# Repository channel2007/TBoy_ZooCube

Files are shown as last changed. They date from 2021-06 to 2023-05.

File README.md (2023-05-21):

# TBoy
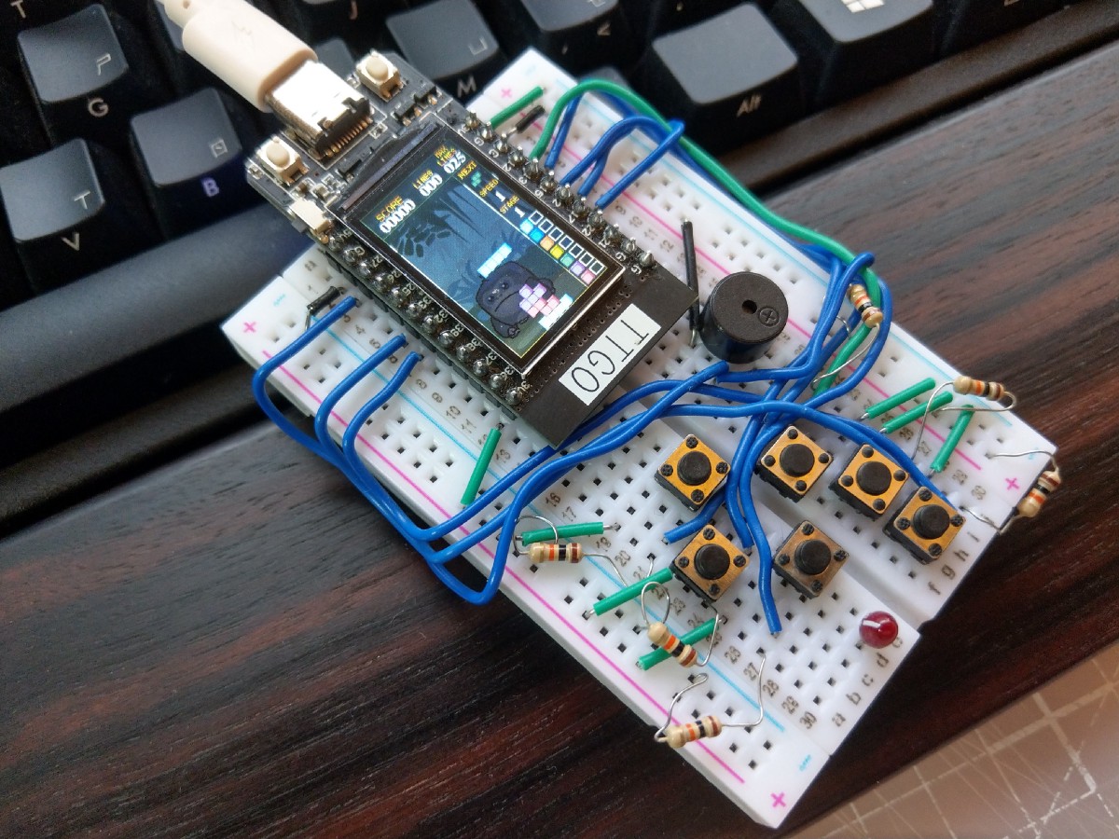
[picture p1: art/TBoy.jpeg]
alt TBoy TBoy


# 研發日誌
* 2023/05/21 新增Pong連線遊戲
* 2023/05/21 調整目錄路徑
* 2021/08/23 新增動物方塊韌體檔案(firmware目錄)
* 2021/07/23 修正遊戲圖形顏色不正確問題
* 2021/06/25 開放EasyEDA顯上線路圖檔案
* 2021/06/24 新增PCB板

# 前言
DIY了幾台網路大神們開源的掌機後，想想也該是時候來弄台原創掌機回饋一下社群了，也就是說新作的這台掌機會開源，希望對有興趣製作掌機的同好有所幫助。

# 準備材料
* TTGO T-Display ESP32 x  1
* 輕觸開關中兩腳 x 6
* 10kΩ電阻 x 6
* 蜂鳴器 x 1
* 麵包板 x 1
* 麵包板線一盒

# 線路圖
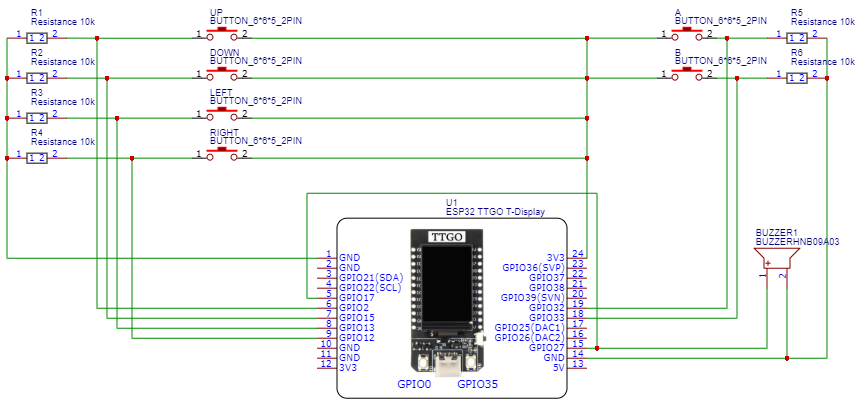
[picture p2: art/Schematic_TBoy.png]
alt TBoy TBoy


# 安裝套件
* [Bodmer/TFT_eSPI](https://github.com/Bodmer/TFT_eSPI)

# ZooCube遊戲介紹
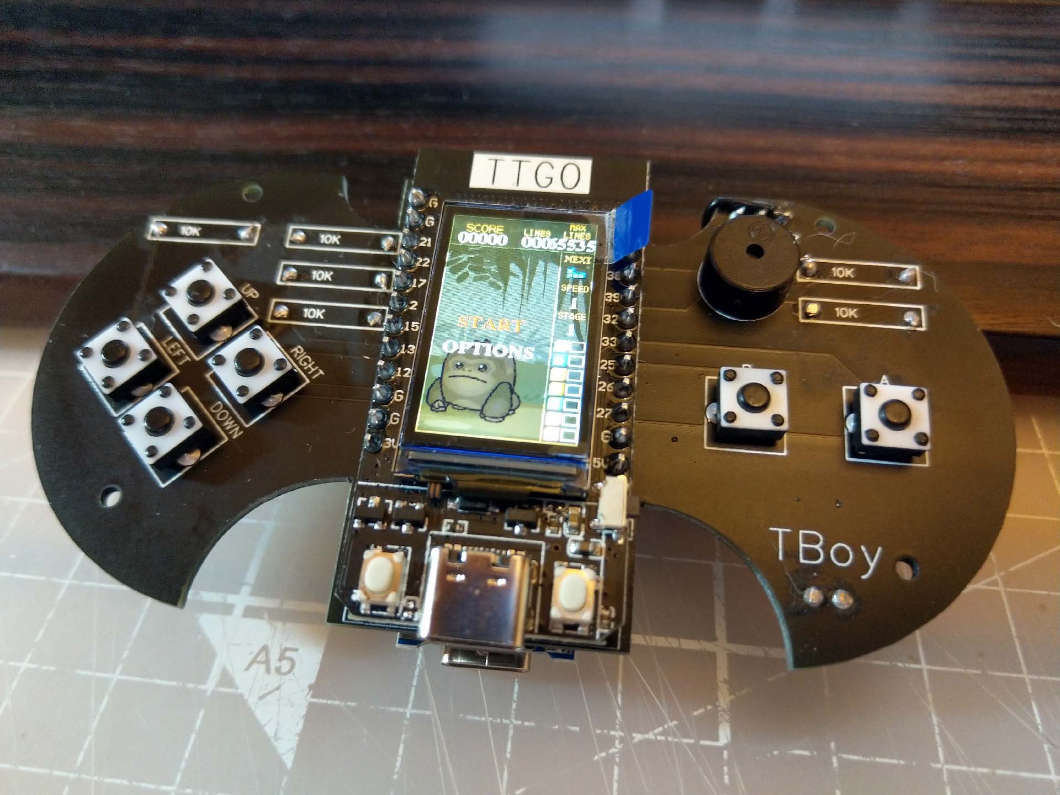
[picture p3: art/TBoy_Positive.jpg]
alt TBoy TBoy

* 遊戲玩法
玩家需要在10x20的空間內控制由上往下掉落的的七種方塊，利用旋轉方塊功能使掉落的方塊連成橫線，啟動消除方塊，如果在20列中都無法連成橫線消除方塊，遊戲就告結束。
遊戲中每消除一列會將每列的方塊顏色作累加，一共有七種顏色的方塊，每種顏色收集滿都會發動不同效果的技能。
隨著消除方塊列的數量越多，方塊下降的速度也會隨之變快，背景也會跟著變換圖片。

# 按鍵說明
* 左右按鈕：移動慢慢掉落中的方塊
* 下按鈕：讓方塊快速掉落
* A按鈕：順時鐘旋轉方塊
* B按鈕：逆時鐘旋轉方塊
* 開始按鈕：暫停遊戲
* 選擇按鈕：選項選單

# 使用網路資源
* [THE SPRITERS RESOURCE](https://www.spriters-resource.com/)
* [robsoncouto/arduino-songs](https://github.com/robsoncouto/arduino-songs)

# Pong連線遊戲介紹
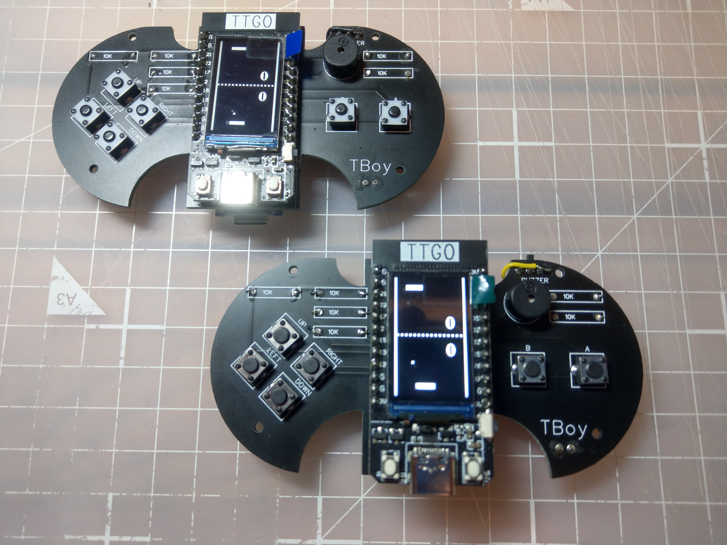
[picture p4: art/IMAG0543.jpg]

* 遊戲玩法
1. 遊戲場地 Pong遊戲的場地是一個矩形，有兩個玩家，一個在上方，一個在下方。每個玩家都有一個橫條（也稱為"板子"或"球拍"），可在水平方向移動。
2. 遊戲物件：遊戲中的主要物件是一個小球，它會在遊戲場地內以一定的速度移動，並且在撞到邊界或玩家的橫條時反彈。
3. 玩家控制：玩家可以左右移動他們的橫條，目的是讓小球反彈回對方的半場。玩家不能超過遊戲場地的邊界。
4. 得分規則：當一方玩家未能成功用橫條接住小球，使其反彈回對方半場時，對方就會得分。也就是說，如果小球碰到你的場地邊界，對方就獲得一分。獲得一定分數的玩家（例如10分）將獲得勝利。
5. 遊戲流程 遊戲開始時，小球從場地中央或隨機的一個點發出，向任一方向移動。遊戲繼續進行，直到一名玩家贏得遊戲，然後開始新的一局

# 按鍵說明
* 上下按鈕：選1P或2P
* 左右按鈕：左右移動板子
* A按鈕：確定、開始遊戲、遊戲中按住加速板子左右移動
* Start按鈕：無敵(球掉落底部自動反彈)
* Select按鈕：自動玩(板子自動追著球的X座標移動)

# PCB板準備材料
* TTGO T-Display ESP32 x 1
* 輕觸開關中兩腳 x 6
* 10kΩ電阻 x 6
* 無源蜂鳴器9*5.5MM  x 1
* 鋰電池充電板模組 TYPE-C USB介面充電保護二合一 x 1
* XH2.54-2P/針座/彎針/白色插件 2.54間距 x 1
* XH2.54-6P/針座/彎針/白色插件 2.54間距 x 1
* 200mAH、3.7V 聚合物鋰電池 x 1
* 滑動開關三腳二檔微型開關 x 1

# EasyEDA線路圖連接
[EasyEDA - TBoy](https://oshwlab.com/channel2007/tboy)

# PCB線路圖
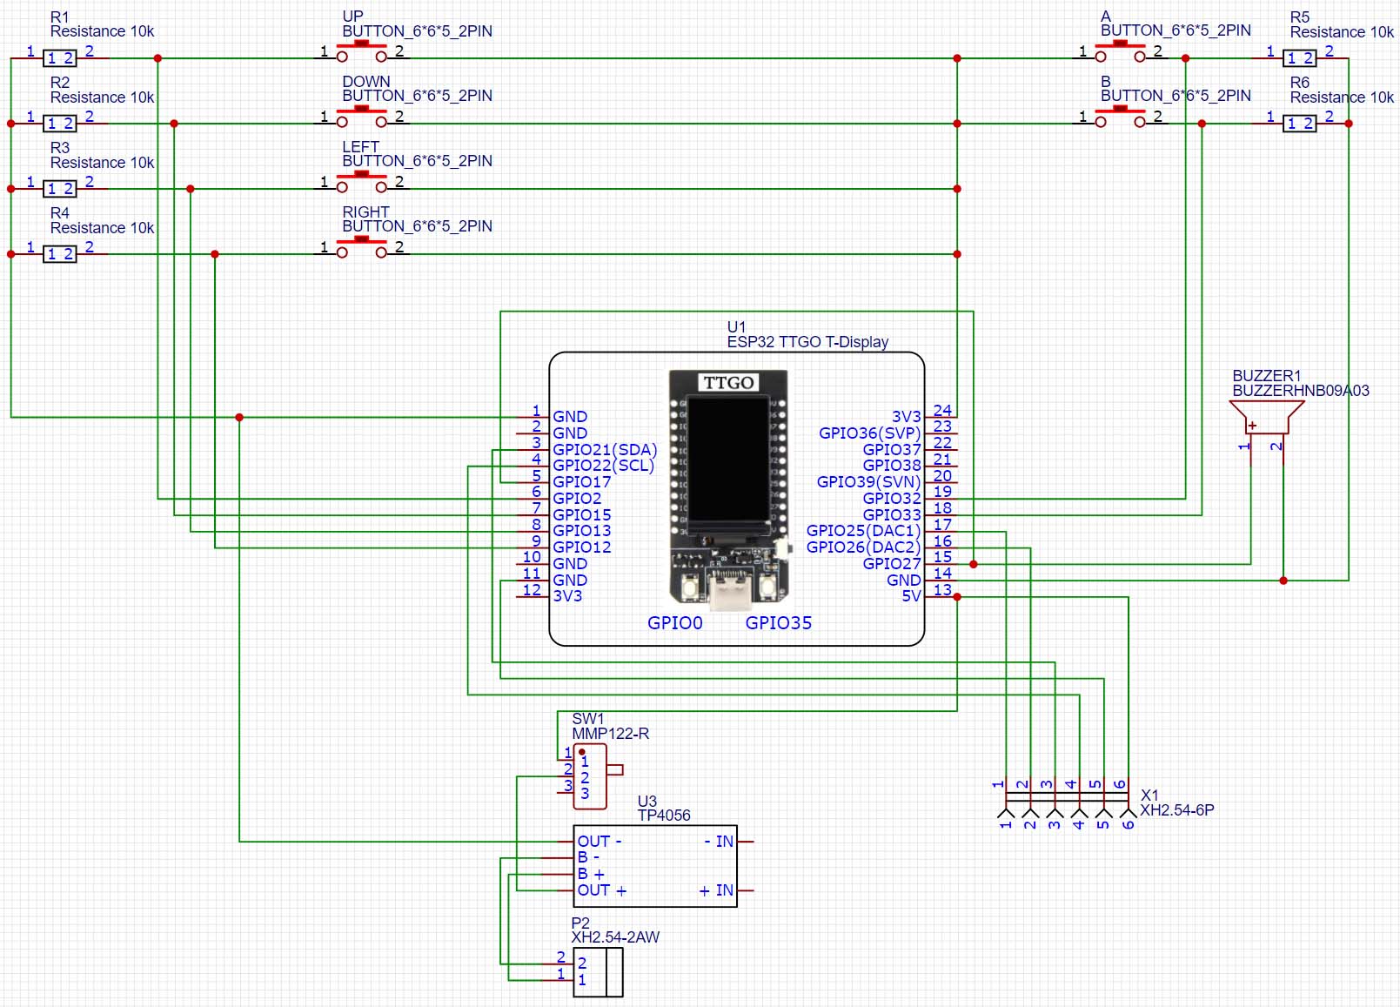
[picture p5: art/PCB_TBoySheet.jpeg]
alt TBoy TBoy

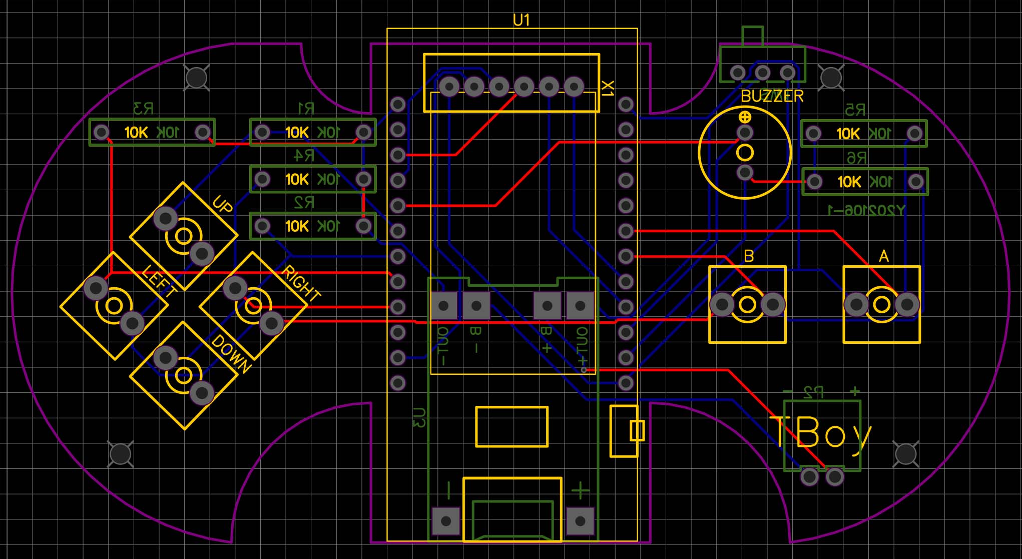
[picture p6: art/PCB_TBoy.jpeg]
alt TBoy TBoy


# 實機照
alt TBoy TBoy
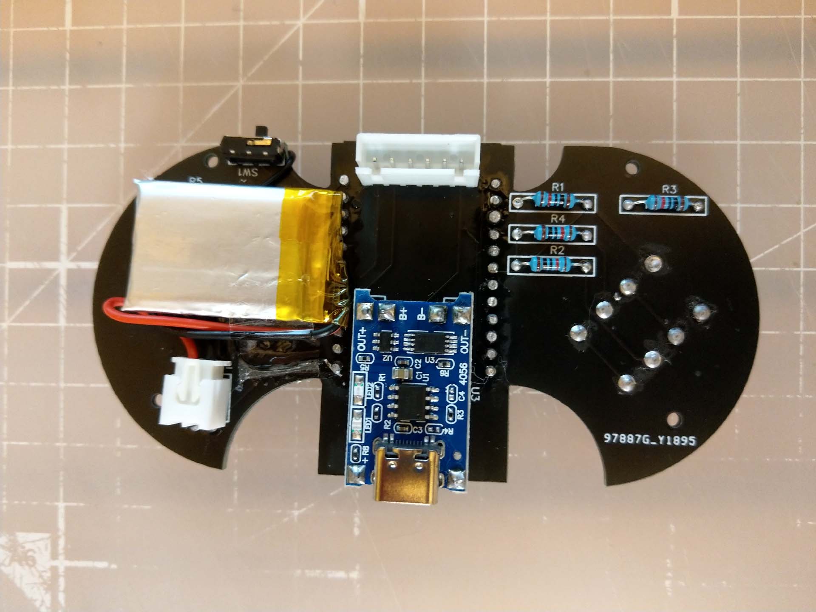
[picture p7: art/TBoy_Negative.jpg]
alt TBoy TBoy


# 詳細解說可以參考筆者寫的文章
[【掌機】原創掌機TBoy](https://vocus.cc/article/60bd70f7fd8978000182d0db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)

# 官方紛絲團 
[無限升級](https://www.facebook.com/unlimited.upgrade/posts/2840132506240869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)

# 官方Youtube
[無限升級](https://www.youtube.com/channel/UC4reRKznNk1CcjZfxKUdMuw)

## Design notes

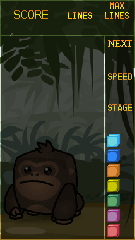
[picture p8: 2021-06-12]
art/ZooCube/background1.png

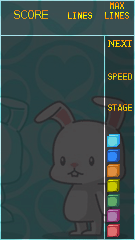
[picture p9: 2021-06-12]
art/ZooCube/background4.png

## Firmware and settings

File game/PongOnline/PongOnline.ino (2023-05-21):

//========================================================
// 功能：Pong連線遊戲 - 主程式.
//
//========================================================
#include <TFT_eSPI.h>
#include <SPI.h>

#include "Free_Fonts.h" 
#include "esp32_wifi_tcp.h"
#include "Joystick.h"
// 0:FPS.
// 1:計算FPS.
// 2:閃爍字.
#include "ClockSystem.h"

#define PADDLE_WIDTH 32           // 板子寬長.
#define PADDLE_HEIGHT 10

#define BALL_WIDTH 4              // 球寬長.
#define BALL_HEIGHT 4

#define WIN_SCORE 10              // 贏幾局結束遊戲.

// 遊戲模式.
typedef enum{
  GAME_SELECT=0,    // 選1P、2P.  
  GAME_CONNECTING,  // 等待連線.
  GAME_BEGIN,       // 準備開始遊戲.
  GAME_PLAY,        // 開始遊戲.
  GAME_OVER         // 遊戲結束.
} GameMode;

// box結構.
typedef struct {
    int x;
    int y;
    int w;
    int h;    
} Box;

// 球結構.
typedef struct {
    double x;
    double y;
    double prevX;
    double prevY;
    int w;
    int h;        
} Ball;

// 建立wifi物件.
esp32_wifi_tcp tcp( true, "ESP32-AP", "12345678");
// SPI.
TFT_eSPI tft = TFT_eSPI(); 
// 備頁.
TFT_eSprite doubleBuffer = TFT_eSprite(&tft);

// 搖桿1P.
Joystick joystick_1P(2, 15, 13, 12, 32, 33, 35, 0);
// 時脈系統.
ClockSystem clockSystem;

// 板子(1P、2P).
Box board1P;
Box board2P;
// 球.
Ball ball;

// fps.
uint8_t fps=0;
uint8_t fpsTemp=0;

// 是否為Server模式(1P).
bool isServer = true;
// 閃爍字.
bool flashFont = true;

// 分數.
uint8_t score1P = 0;
uint8_t score2P = 0;
// 球-移動速度.
double speed = 2.0;
// 球-設定初始反射角度.
double reflection_angle = 45.0;  

// 行進時間(時間越長球速越快).
int travelTime = 0;
// 無敵.
bool invincible= false;
// 自動玩遊戲.
bool autoPlay = false;
// 板子移動速度.
int boardSpeed = 4;

// 字串.
char buf[64]; 

// 設定初始狀態.
GameMode gameMode = GAME_SELECT;

//-----------------------------------------------------
// 拆解字串.
//-----------------------------------------------------
void split(const char *data, char separator, char result[][100], int *resultCount, int maxResultCount) {
  int len = strlen(data);
  int start = 0;
  int end = 0;
  *resultCount = 0;
  for (int i = 0; i < len; i++) {
    if (data[i] == separator) {
      end = i;
      int length = end - start;
      if (length > 0) {
        strncpy(result[*resultCount], &data[start], length);
        result[*resultCount][length] = '\0';
        (*resultCount)++;
        if (*resultCount >= maxResultCount) {
          break;
        }
      }
      start = i + 1;
    }
  }  
  if (*resultCount < maxResultCount) {
    int length = len - start;
    if (length > 0) {
      strncpy(result[*resultCount], &data[start], length);
      result[*resultCount][length] = '\0';
      (*resultCount)++;
    }
  }
}

//-----------------------------------------------------
// 判斷球與板子碰撞.
//-----------------------------------------------------
bool didCollide(Box p, Ball b){
  // 首先檢查球是否在板子的左邊或右邊之外，如果是，則不可能發生碰撞
  if ((b.x + BALL_WIDTH / 2.0) < p.x || (b.x - BALL_WIDTH / 2.0) > (p.x + PADDLE_WIDTH)) {
    return false;
  }
  // 檢查球是否在板子的上邊或下邊之外，如果是，則不可能發生碰撞
  if ((b.y + BALL_HEIGHT / 2.0) < p.y || (b.y - BALL_HEIGHT / 2.0) > (p.y + PADDLE_HEIGHT)) {
    return false;
  }
  // 如果以上條件都不成立，則表示球與板子有重疊，即發生了碰撞
  return true;
}

//-----------------------------------------------------
// 更新球移動.
//-----------------------------------------------------
void updateBall(Ball* position, double* speed, double* reflection_angle) {
    // 遊戲中才進入處理球移動.
    if(gameMode != GAME_PLAY)
      return;
    
    // 計算球在x軸和y軸上的速度成分
    double dx = *speed * cos(*reflection_angle);
    double dy = *speed * sin(*reflection_angle);

    // 備份球舊座標(判斷碰撞用).
    position->prevX = position->x; 
    position->prevY = position->y;

    // 更新球的位置
    position->x += dx;
    position->y += dy;

    // 檢查是否碰到邊界，並反彈
    if (position->x < 4  || position->x > 127) {
      // 球碰到左右邊界，將反射角度反轉
      *reflection_angle = M_PI - *reflection_angle;
    }
    if (position->y < 0 || position->y > 240) {
      // 球碰到上下邊界，將反射角度反轉
      *reflection_angle = -(*reflection_angle);
      // 不是無敵才進入執行.
      if(!invincible){
        // 1P加分.
        if(position->y < 0){
          score1P++;        
        // 2P加分.
        }else if(position->y > 240){
          score2P++;
        }  
        // 初始球位置.
        position->x = position->prevX = 70; 
        position->y = position->prevY = 120;
        
        // 放慢球速.
        *speed = 2.0;
        //Serial.println((String)position->x+":"+position->y);      
      }      
    }
}

//-----------------------------------------------------
// 更新畫面.
//-----------------------------------------------------
void updateScreen(){
  // 牆壁-左.
  doubleBuffer.fillRect (  0, 0,  4,  240, 0xFFFF);    
  // 牆壁-右.
  doubleBuffer.fillRect (131, 0,  4,  240, 0xFFFF);
  // 牆壁-中.      
  for(int i=4; i<131; i+=8){
    doubleBuffer.fillRect (i, 118, 4,  4, 0xFFFF);
  }
  // 顯示分數.
  doubleBuffer.setFreeFont(FSB18);
  doubleBuffer.setTextColor(TFT_WHITE, TFT_BLACK);      
  sprintf(buf, "%d", score2P);
  doubleBuffer.drawCentreString(buf, 105,  80, GFXFF); // 2P.
  sprintf(buf, "%d", score1P);
  doubleBuffer.drawCentreString(buf, 105, 135, GFXFF); // 1P.  

  // 板子1P. 
  doubleBuffer.fillRect ( board1P.x, board1P.y, board1P.w,  board1P.h, 0xFFFF);
  // 板子2P. 
  doubleBuffer.fillRect ( board2P.x, board2P.y, board2P.w,  board2P.h, 0xFFFF);   
}

//-----------------------------------------------------
// 顯示連線訊息.
//-----------------------------------------------------
void connecting(){
  // 用全黑清除螢幕
  doubleBuffer.fillScreen(TFT_BLACK);
  doubleBuffer.setFreeFont(FSB9);
  doubleBuffer.setTextColor(TFT_WHITE, TFT_RED);
  doubleBuffer.drawCentreString("connecting...", 66, 40, GFXFF);
  // 更新畫面.
  updateScreen();  
}

//-----------------------------------------------------
// 板子超界修正.
//-----------------------------------------------------
void boardOverstep(){  
  if(board1P.x<4) 
    board1P.x = 4;          
  if(board2P.x<4) 
    board2P.x = 4;        
  if(board1P.x>99) 
    board1P.x = 99;          
  if(board2P.x>99) 
    board2P.x = 99;
}

//-----------------------------------------------------
// 移動板子.
//-----------------------------------------------------
void boardMove(){
  // 左.
  if (joystick_1P.GetButtonLeft(false)) {
    // 1P.
    if(isServer){
      board1P.x -= boardSpeed;
    // 2P.
    }else{
      board2P.x -= boardSpeed;
    }
    
  // 右.
  }else if (joystick_1P.GetButtonRight(false)) {
    // 1P.
    if(isServer){
      board1P.x += boardSpeed;
    // 2P.
    }else{
      board2P.x += boardSpeed;
    }        

  // 開關無敵.
  }else if (joystick_1P.GetButtonStart(true)) {
    invincible = !invincible;
    
  // 開關自動玩.
  }else if (joystick_1P.GetButtonSelect(true)) {
    autoPlay = !autoPlay;
        
  }

  // 快速移動板子.
  if (joystick_1P.GetButtonA(false)){
    boardSpeed = 12;
  }else{
    boardSpeed = 4;
  }
  
  // 板子超界修正.
  boardOverstep();  
}

//-----------------------------------------------------
// 1P、2P相互溝通.
//-----------------------------------------------------
void communicate(){
  // Server模式(1P).
  if(isServer){
    // 【Server傳送指令給Client】1P板子座標 - c1|x|bx|by|score1P|score2P|gameMode|
    sprintf(buf, "c1|%d|%f|%f|%d|%d|%d|", board1P.x, ball.x, ball.y, score1P, score2P, gameMode);
    tcp.send(buf);
          
    // 更新球.
    updateBall(&ball, &speed, &reflection_angle);
      
    // 如果球與板子發生碰撞就處理反彈.       
    if( didCollide(board1P, ball) || didCollide(board2P, ball)){
      // 反彈球.
      reflection_angle = -(reflection_angle);
      // 復原座標.
      ball.x = ball.prevX; ball.y = ball.prevY;
      // 開球時放慢速度，等碰到板子後恢復正常速度.
      if(speed == 2.0) speed = 4.0;
    }    
    //Serial.println(str);

    // 自動玩.
    if(autoPlay){
      board1P.x = ball.x -(PADDLE_WIDTH - BALL_WIDTH)/2;
    }
           
  // Client模式(2P).
  }else{
    //【Client傳送指令給Server】2P板子座標 - s1|x|
    sprintf(buf, "s1|%d|", board2P.x);
    tcp.send(buf);

    // 自動玩.
    if(autoPlay){
      board2P.x = ball.x-(PADDLE_WIDTH - BALL_WIDTH)/2;
    }    
  }
  // 板子超界修正.
  boardOverstep();  
}

//-----------------------------------------------------
// 重新開始遊戲.
//-----------------------------------------------------
void resetGame(){
  // 球.
  ball.x = ball.prevX = 70; ball.y = ball.prevY = 120;
  // 分數.
  score1P = 0;
  score2P = 0;
  // 球-移動速度.
  speed = 2.0;
  // 行進時間(時間越長球速越快).
  travelTime = 0;
  // 板子移動速度.
  boardSpeed = 4;  
}

//-----------------------------------------------------
// 解指令字串.
//-----------------------------------------------------
void decodingReceived(String received){
  char result[10][100];   // 用來存放分割後的字串，最多容納 10 個字串，每個字串長度最多 100 個字元.
  int resultCount = 0;    // 儲存分割後的字串數量.
  int n = 0;
  double d = 0.0;
  
  if(received=="")
    return;
    
  // 需要多一個字元來容納結尾的 null 字元
  char charArray[received.length() + 1];  

  // 將 String 轉換為 char 字元陣列
  received.toCharArray(charArray, sizeof(charArray));
  // 解指令字串.
  split( charArray, '|', result, &resultCount, 10);

  //【Client(2p)傳送指令給Server(1p)】板子座標.
  // 指令格式：s1|x|
  if(String(result[0])=="s1"){
    n = String(result[1]).toInt();
    board2P.x = n;
    
  //【Server(1p)傳送指令給Client(2p)】板子座標、球資料.
  // 指令格式：c1|x|bx|by|score1P|score2P|gameMode|
  }else if(String(result[0])=="c1"){
    // x.
    n = String(result[1]).toInt();
    board1P.x = n;
    // bx.
    d = String(result[2]).toDouble();
    ball.x = d;    
    // by.
    d = String(result[3]).toDouble();
    ball.y = d;        
    // score1P.
    n = String(result[4]).toInt();
    score1P = n;
    // score2P.
    n = String(result[5]).toInt();
    score2P = n;
    // gameMode.
    n = String(result[6]).toInt();
    gameMode = (GameMode)n;   
  }  
}

//-----------------------------------------------------
// 初始.
//-----------------------------------------------------
void setup() {
  Serial.begin(115200);
  
  // 初始化LCD
  tft.begin();                  
  tft.setSwapBytes(true);

  // 螢幕方向(0:正 2:反).
  tft.setRotation(0);
  
  // 初始時脈系統.
  clockSystem.initClock();
 
  // 建立備頁(精靈).
  doubleBuffer.setColorDepth(16);
  doubleBuffer.createSprite(135, 240);      
    
  // 板子1P.
  board1P.x = 54; board1P.y =  16; board1P.w = PADDLE_WIDTH;board1P.h = PADDLE_HEIGHT;
  // 板子2P.
  board2P.x = 54; board2P.y = 216; board2P.w = PADDLE_WIDTH;board2P.h = PADDLE_HEIGHT;
  // 球.  
  ball.x = ball.prevX = 70; ball.y = ball.prevY = 120;
  ball.w = BALL_WIDTH; ball.h = BALL_HEIGHT;
}

//-----------------------------------------------------
// 主迴圈.
//-----------------------------------------------------
void loop() {  
  // 計算FPS.
  if (clockSystem.checkClock(1, 1000)) {
    fps=fpsTemp;
    fpsTemp=0; 
    travelTime++;   
  }

  // FPS 60.
  if (clockSystem.checkClock(0, 17)) {
    fpsTemp++;
        
    // 解指令字串.
    decodingReceived(tcp.receive());    
    // 清除螢幕.
    doubleBuffer.fillScreen(TFT_BLACK);
    
    // 選1P、2P.
    if(gameMode == GAME_SELECT){
      //--------------------------------------------
      // 顯示.
      //--------------------------------------------    
      // 更新畫面.
      updateScreen();
      
      // 顯示字.
      doubleBuffer.setFreeFont(FSSBO24);
      doubleBuffer.setTextColor(TFT_WHITE, TFT_BLACK);
      doubleBuffer.drawCentreString("1P", 50,  35, GFXFF);
      doubleBuffer.drawCentreString("2P", 50, 160, GFXFF);
    
      // 顯示選到的模式(1P Server ， 2P Client).
      doubleBuffer.setTextColor(TFT_WHITE, TFT_RED);
      if(isServer)
        doubleBuffer.drawCentreString("1P", 50,  35, GFXFF);
      else
        doubleBuffer.drawCentreString("2P", 50, 160, GFXFF);
    
      //--------------------------------------------
      // 輸入.
      //--------------------------------------------
      // 上.
      if (joystick_1P.GetButtonUp(true)) {
        isServer = true;
      // 下.
      }else if (joystick_1P.GetButtonDown(true)) {
        isServer = false;
      }
      // A.
      if (joystick_1P.GetButtonA(true)||joystick_1P.GetButtonB(true)){

        // 連線訊息.
        connecting();
        // 更新備頁.
        doubleBuffer.pushSprite(0, 0, 0x07E0);

        // 進入等待連線.
        gameMode = GAME_CONNECTING;
        
        // 設定建立Server或Client.
        tcp.isServer = isServer;
        tcp.begin();
      }    

    // 等待連線.
    }else if(gameMode == GAME_CONNECTING){    
      // 連線訊息.
      connecting();     
      
      // 設定進入準備開始遊戲.
      if(tcp.isConnect()){
        // tcp.send("conn");
        gameMode = GAME_BEGIN;
      }
            
    // 準備開始遊戲.
    }else if(gameMode == GAME_BEGIN){
      // 更新畫面.
      updateScreen();  
      
      // 顯示訊息.
      doubleBuffer.setFreeFont(FSB9);
      if(flashFont)
        doubleBuffer.setTextColor(TFT_WHITE);
      else
        doubleBuffer.setTextColor(TFT_BLACK);

      // 1P.
      if(isServer){
        // A.
        if (joystick_1P.GetButtonA(true)){
          // 球.  
          ball.x = 70; ball.y = 120;
          // 開始遊戲.
          gameMode = GAME_PLAY;
        }
        doubleBuffer.drawCentreString("press A start", 66, 40, GFXFF);        
      // 2P.
      }else{
        doubleBuffer.drawCentreString("waiting...", 66, 40, GFXFF);
      }
                   
      // 閃爍字.
      if (clockSystem.checkClock(2, 1000))
        flashFont =!flashFont;

      // 判斷輸入移動板子.
      boardMove();
      
      // 1P、2P相互溝通.
      communicate();
                  
    // 開始遊戲.
    }else if(gameMode == GAME_PLAY){    
      // 更新畫面.
      updateScreen();
      // 判斷輸入移動板子.
      boardMove();
      // 1P、2P相互溝通.
      communicate();

      // 顯示球. 
      doubleBuffer.fillRect ( ball.x, ball.y, ball.w,  ball.h, 0xFFFF);

      // 遊戲結束.
      if(score1P >= WIN_SCORE || score2P >= WIN_SCORE)
        gameMode = GAME_OVER;

      // 增加球移動速度.
      if((travelTime%10)==0){
        travelTime++;
        speed++;        
        if(speed>8)
          speed = 8;
        //Serial.println(speed);
      }
        
    // 遊戲結束.
    }else if(gameMode == GAME_OVER){
      // 更新畫面.
      updateScreen();      
      // 1P.
      if(isServer){
        // A.
        if (joystick_1P.GetButtonA(true)){
          // 重新開始遊戲.  
          resetGame();          
          // 開始遊戲.
          gameMode = GAME_BEGIN;
        }        
      }
      // 判斷輸入移動板子.
      boardMove();
      // 1P、2P相互溝通.
      communicate();

      // 顯示字.
      doubleBuffer.setFreeFont(FSSO12);
      doubleBuffer.setTextColor(TFT_WHITE, TFT_RED);
      if(score1P >= WIN_SCORE){
        doubleBuffer.drawCentreString("LOSE", 50,  45, GFXFF);
        doubleBuffer.drawCentreString("WIN", 50, 170, GFXFF);
      }else{
        doubleBuffer.drawCentreString("WIN", 50,  45, GFXFF);
        doubleBuffer.drawCentreString("LOSE", 50, 170, GFXFF);        
      }
    }
    
    /*
    // FPS.
    sprintf(buf, "FPS:%d", fps);
    doubleBuffer.setFreeFont(FSB9);
    doubleBuffer.setTextColor(TFT_WHITE);    
    doubleBuffer.drawCentreString(buf, 40, 100, GFXFF);    
    */    
    // 將備頁(精靈)複製到顯示區.
    doubleBuffer.pushSprite(0, 0, 0x07E0);
  }     

}

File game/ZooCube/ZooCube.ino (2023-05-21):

#include <TFT_eSPI.h> #include <SPI.h>

#include "Free_Fonts.h" 
#include "ClockSystem.h"
#include "Joystick.h"
#include "Music.h"
#include "GamePlay.h"

TFT_eSPI tft = TFT_eSPI(); 
TFT_eSprite doubleBuffer = TFT_eSprite(&tft);

Joystick joystick_1P(2, 15, 13, 12, 32, 33, 35, 0);
ClockSystem clockSystem;
GamePlay gamePlay = GamePlay();

typedef enum{
  MENU_MAIN,        
  MENU_OPTIONS,     
  GAME_PLAY,        
  GAME_PAUSE,       
  GAME_OPTIONS,     
  GAME_OVER,      
}GameMode;

char buf[16]; 

uint8_t fps=0;
uint8_t fpsTemp=0;

uint8_t obstacle=0;
uint8_t obstacleGameOver=0;

uint8_t sel=0;
bool  releaseBnt=true;

GameMode gameMode = MENU_MAIN;
GameMode gameModeTemp = MENU_MAIN;
  
void musicEffect(void *pvParam){
  while(1){
        if(gamePlay.gameData.MusicSwitch){
      if(gameMode >= MENU_MAIN && gameMode <= MENU_OPTIONS)
        playChannel();
      else if(gameMode >= GAME_PLAY && gameMode <= GAME_OVER)
        playTetris();
    }        
    tone(BUZZER_DUMMY_PIN, 1, 1000);
    noTone(BUZZER_DUMMY_PIN);    
  }
}

void setup() {
  
  tft.begin();                          
  tft.setSwapBytes(true);

  doubleBuffer.setColorDepth(16);  
  doubleBuffer.createSprite(135, 240);    

  clockSystem.initClock();
  
  gamePlay.copyToGamingZone( gamePlay.cubeX, gamePlay.cubeY, gamePlay.cubeId, gamePlay.cubeState, true);
  
  EEPROM_Init(22);  
  

  gamePlay.GameLoad();

        
  gamePlay.cubeLineMax = gamePlay.gameData.RankingLineMax[0];

  if(gamePlay.gameData.ScreenRotation == 0)
    tft.setRotation(0);
  else
    tft.setRotation(2);

  xTaskCreate(musicEffect, "musicEffect", 1000, NULL, 1, NULL);    
}

void loop() {
    uint8_t cubeID = gamePlay.nextCubeId;  
  uint8_t x=0,y=0,w=0,h=0;
  float cubeMax,cubeNow;

    if (clockSystem.checkClock(1, 1000)) {
    fps=fpsTemp;
    fpsTemp=0;
  }

    if (clockSystem.checkClock(0, 33)) {
    fpsTemp++;
    
    if(gameMode == MENU_MAIN){      
      if (joystick_1P.GetButtonUp(true)) {
        if(sel>=1)
          sel--;
                
      }else if (joystick_1P.GetButtonDown(true)) {
        if(sel<1)
          sel++;
      }
      
      if (joystick_1P.GetButtonA(true) || joystick_1P.GetButtonStart(true)) {
        if(sel==0){
          
          gamePlay.gameReset();          
          
          playMusic = false;
          gameMode = GAME_PLAY;
        }else if(sel==1){
          gameModeTemp = gameMode;
          gameMode = MENU_OPTIONS;
        }
        sel=0;  
      }
    
    }else if(gameMode == MENU_OPTIONS || gameMode == GAME_OPTIONS){
      if (joystick_1P.GetButtonUp(true)) {
        if(sel>=1)
          sel--;
      
      }else if (joystick_1P.GetButtonDown(true)) {
        if(sel<3)
          sel++;
      }      
      
      if (joystick_1P.GetButtonA(true) || joystick_1P.GetButtonStart(true)) {
        
        if(sel==0){          
          gamePlay.gameData.MusicSwitch = !gamePlay.gameData.MusicSwitch;
          
          if(!gamePlay.gameData.MusicSwitch)
            playMusic = false;                      
          if(EEPROM_ENABLE)
            EEPROM_writeByte(gamePlay.gameData.MusicSwitch, 2);                    
        }else if(sel==1){
          gamePlay.gameData.SoundSwitch = !gamePlay.gameData.SoundSwitch;                              
          if(EEPROM_ENABLE)
            EEPROM_writeByte(gamePlay.gameData.SoundSwitch, 3);
          
        
        }else if(sel==2){
          if(gamePlay.gameData.ScreenRotation==0){
            gamePlay.gameData.ScreenRotation = 2;
            tft.setRotation(2);              
          }else{
            gamePlay.gameData.ScreenRotation = 0;
            tft.setRotation(0);
          }
          if(EEPROM_ENABLE)
            EEPROM_writeByte(gamePlay.gameData.ScreenRotation, 1);
        }else if(sel==3){
          gamePlay.clearGamingZone(0);     
          gamePlay.update();
          playMusic = false;          
          obstacle=0;
          obstacleGameOver=0;          
          gameMode = MENU_MAIN;          
          sel=0;       
        }        
      }
      
      if (joystick_1P.GetButtonB(true) || joystick_1P.GetButtonSelect(true)) {
        gameMode = gameModeTemp;
        sel=0;
      }
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

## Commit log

2021-06-24 新增PCB板
    [Gerber_BoardOutline.GKO, Gerber_BottomLayer.GBL, Gerber_BottomSilkLayer.GBO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]
2021-07-23 修正遊戲圖顏色不正確問題
2021-08-23 新增韌體檔案(firmware目錄)
2021-08-23 Add files via upload
    新增動物方塊韌體檔案
2023-05-21 新增Pong連線遊戲
